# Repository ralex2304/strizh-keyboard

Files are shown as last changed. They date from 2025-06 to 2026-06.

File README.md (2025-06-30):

# [WIP] Strizh keyboard

**Strizh** (Russian for "swift") is an ultra low profile 44-48 key split with Kailh PG1316S switches

## Planned features

- ~9 mm thickness

- ZMK firmware

- NRF52840 SuperMini controllers

- optional 40 mm Cirque trackpad

- optional nice!view display

## PCB Draft

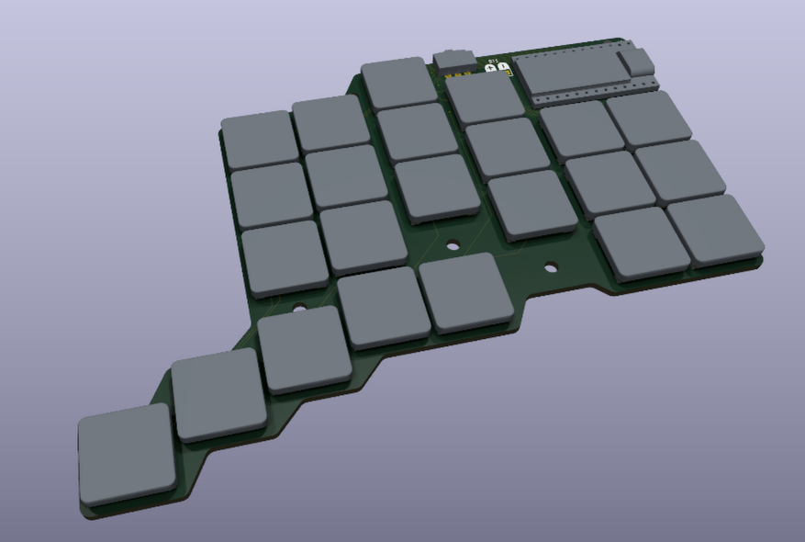
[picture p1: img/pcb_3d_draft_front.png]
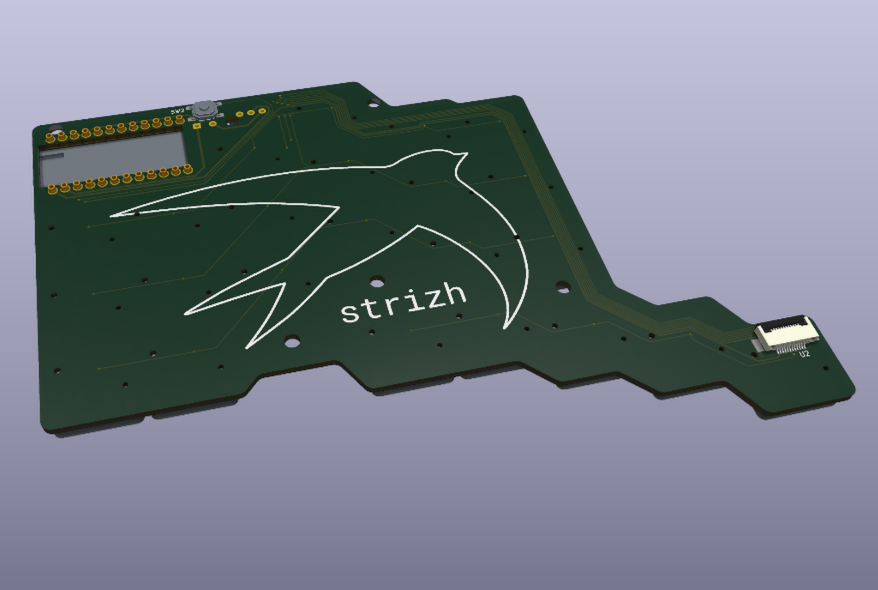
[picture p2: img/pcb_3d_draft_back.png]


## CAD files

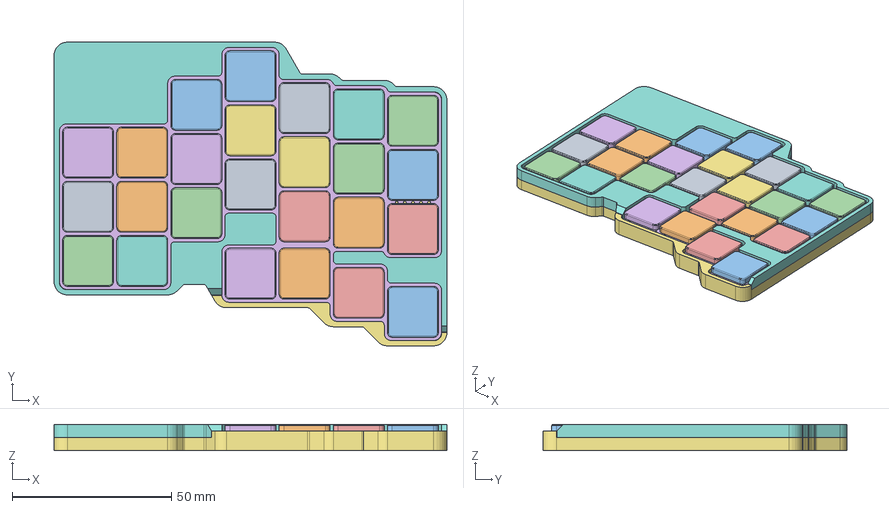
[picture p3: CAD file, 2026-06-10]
3D/case-left-7col/case-left-7col.FCStd
123.4 x 95.4 x 8.21 mm
sw_spst_5.2_5.2_1.5
left-7col_PCB

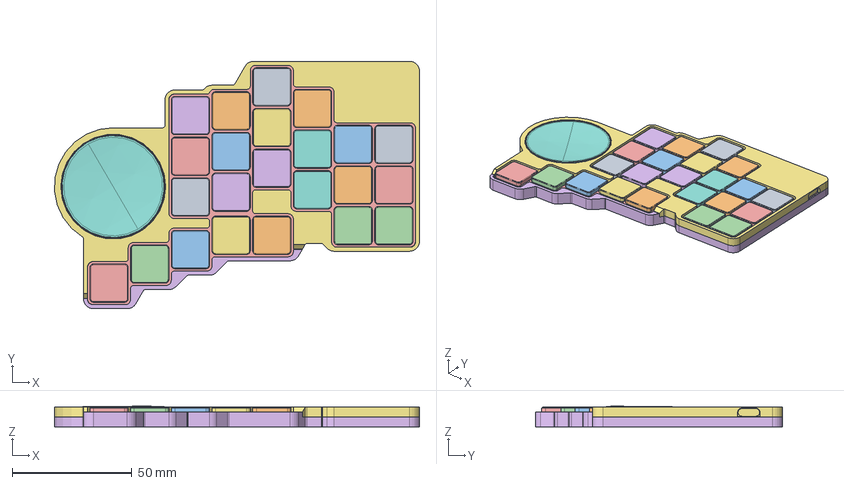
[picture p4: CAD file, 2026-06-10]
3D/case-right-trackpad/case-right-trackpad.FCStd
152.5 x 103.4 x 8.58 mm
sw_spst_5.2_5.2_1.5
FPC-12
FPC-013
FPC-014
FPC-015
FPC-016
FPC-017
FPC-018
FPC-019
FPC-020
FPC-021
FPC-022
FPC-023
FPC-024
FPC-025
FPC-026
FPC-027
FPC-028
right-trackpad_PCB

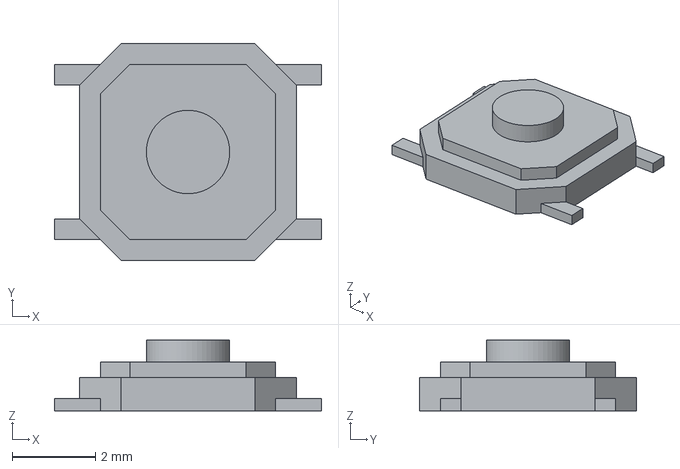
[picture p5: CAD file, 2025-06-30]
pcb/3D/sw_spst_5.2_5.2_1.5.step
6.40 x 5.20 x 1.70 mm

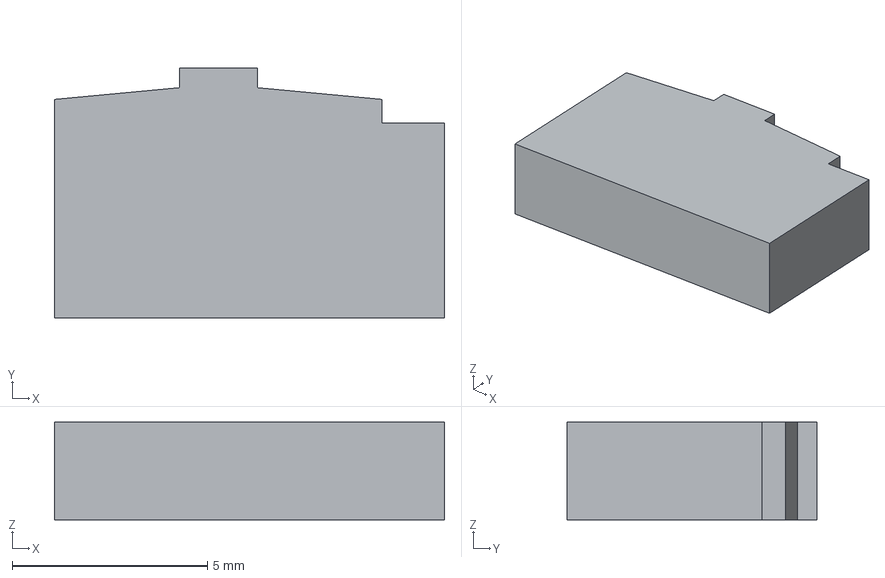
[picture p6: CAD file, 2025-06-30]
pcb/3D/bsi-10h.step
10.0 x 6.40 x 2.50 mm

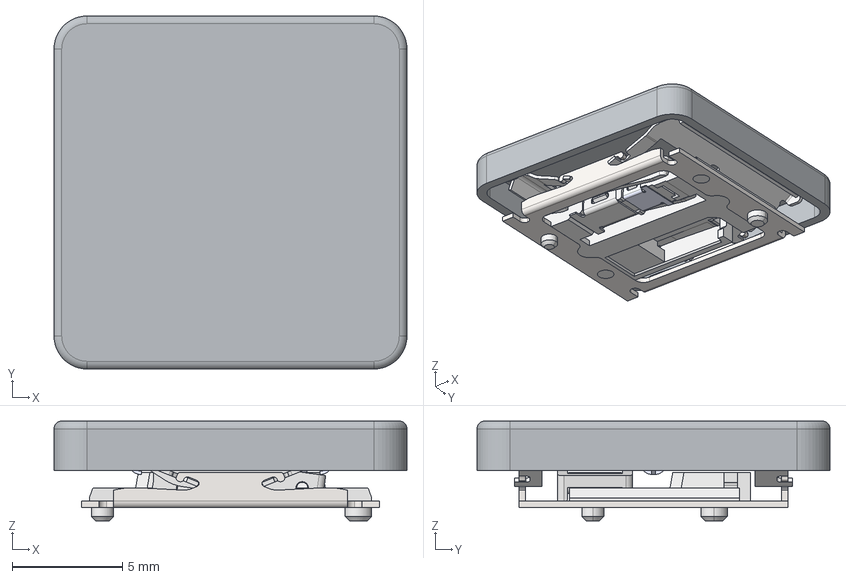
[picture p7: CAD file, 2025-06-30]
pcb/3D/PG1316S.step
16.0 x 16.0 x 4.53 mm
base
insolator
lever
left-wing
spring
right-pin
left-pin
right-wing

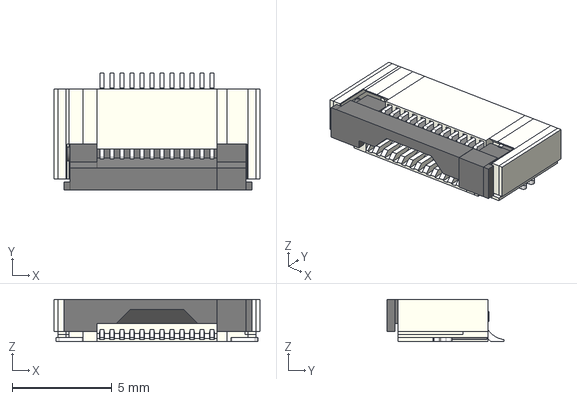
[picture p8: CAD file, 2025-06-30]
pcb/3D/FPC-12.stp
10.3 x 5.85 x 2.11 mm

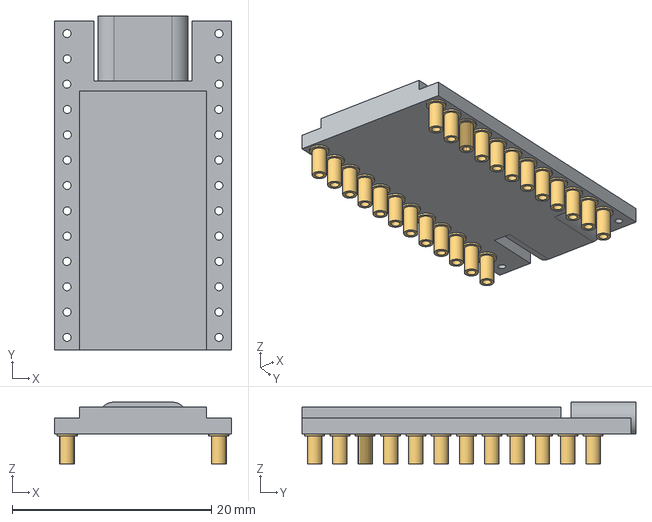
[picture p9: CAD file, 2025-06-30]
pcb/3D/supermini.step
17.8 x 33.5 x 6.20 mm

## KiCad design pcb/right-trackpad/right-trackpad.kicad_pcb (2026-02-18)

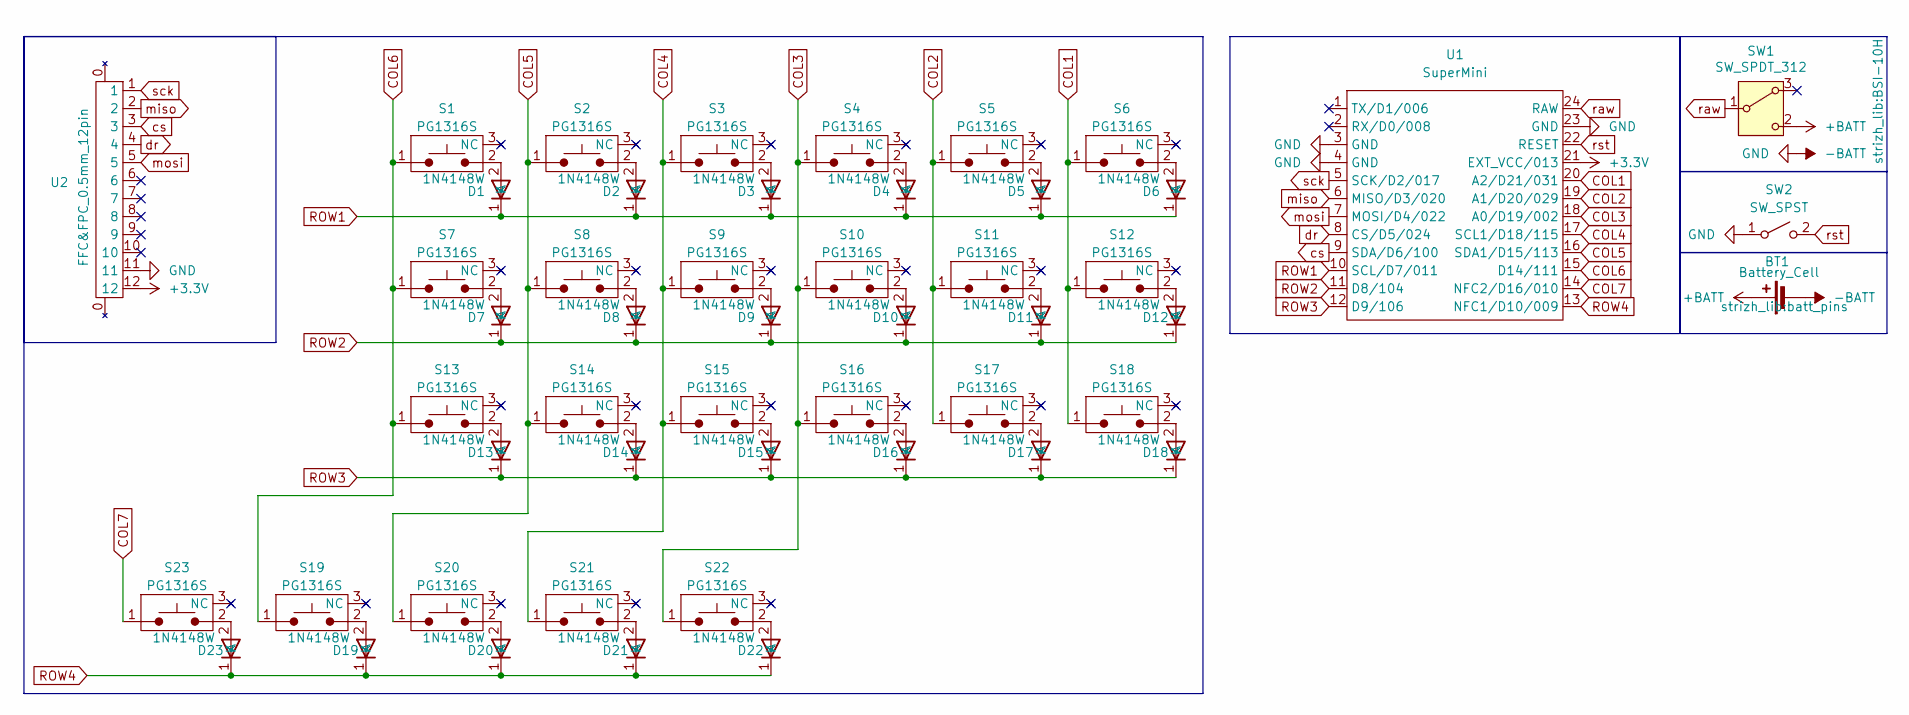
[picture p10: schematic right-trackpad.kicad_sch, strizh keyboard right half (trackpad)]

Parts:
BT1: Battery_Cell; batt_pins
D1, D2, D3, D4, D5, D6, D7, D8, D9, D10, D11, D12, D13, D14, D15, D16, D17, D18, D19, D20, D21, D22, D23: 1N4148W; 1N4148W_SOD-123
S1, S2, S3, S4, S5, S6, S7, S8, S9, S10, S11, S12, S13, S14, S15, S16, S17, S18, S19, S20, S21, S22, S23: PG1316S
SW1: SW_SPDT_312; BSI-10H
SW2: SW_SPST; SW_SPST_SKQG_WithStem
U1: SuperMini; supermini_nrf52840
U2: FFC&FPC_0.5mm_12pin

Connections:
+3.3V: U1.21 (EXT_VCC/013), U2.12
+BATT: BT1.1 (+), SW1.2 (C)
-BATT: BT1.2 (-), SW2.1 (A), U1.3 (GND), U1.4 (GND), U1.23 (GND), U2.11
COL1: S6.1, S12.1, S18.1, U1.20 (A2/D21/031)
COL2: S5.1, S11.1, S17.1, U1.19 (A1/D20/029)
COL3: S4.1, S10.1, S16.1, S22.1, U1.18 (A0/D19/002)
COL4: S3.1, S9.1, S15.1, S21.1, U1.17 (SCL1/D18/115)
COL5: S2.1, S8.1, S14.1, S20.1, U1.16 (SDA1/D15/113)
COL6: S1.1, S7.1, S13.1, S19.1, U1.15 (D14/111)
COL7: S23.1, U1.14 (NFC2/D16/010)
unnamed: D1.2 (A), S1.2
unnamed: D2.2 (A), S2.2
unnamed: D3.2 (A), S3.2
unnamed: D4.2 (A), S4.2
unnamed: D5.2 (A), S5.2
unnamed: D6.2 (A), S6.2
unnamed: D7.2 (A), S7.2
unnamed: D8.2 (A), S8.2
unnamed: D9.2 (A), S9.2
unnamed: D10.2 (A), S10.2
unnamed: D11.2 (A), S11.2
unnamed: D12.2 (A), S12.2
unnamed: D13.2 (A), S13.2
unnamed: D14.2 (A), S14.2
unnamed: D15.2 (A), S15.2
unnamed: D16.2 (A), S16.2
unnamed: D17.2 (A), S17.2
unnamed: D18.2 (A), S18.2
unnamed: D19.2 (A), S19.2
unnamed: D20.2 (A), S20.2
unnamed: D21.2 (A), S21.2
unnamed: D22.2 (A), S22.2
unnamed: D23.2 (A), S23.2
ROW1: D1.1 (K), D2.1 (K), D3.1 (K), D4.1 (K), D5.1 (K), D6.1 (K), U1.10 (SCL/D7/011)
ROW2: D7.1 (K), D8.1 (K), D9.1 (K), D10.1 (K), D11.1 (K), D12.1 (K), U1.11 (D8/104)
ROW3: D13.1 (K), D14.1 (K), D15.1 (K), D16.1 (K), D17.1 (K), D18.1 (K), U1.12 (D9/106)
ROW4: D19.1 (K), D20.1 (K), D21.1 (K), D22.1 (K), D23.1 (K), U1.13 (NFC1/D10/009)
cs: U1.9 (SDA/D6/100), U2.3
dr: U1.8 (CS/D5/024), U2.4
miso: U1.6 (MISO/D3/020), U2.2
mosi: U1.7 (MOSI/D4/022), U2.5
raw: SW1.1 (B), U1.24 (RAW)
rst: SW2.2 (B), U1.22 (RESET)
sck: U1.5 (SCK/D2/017), U2.1

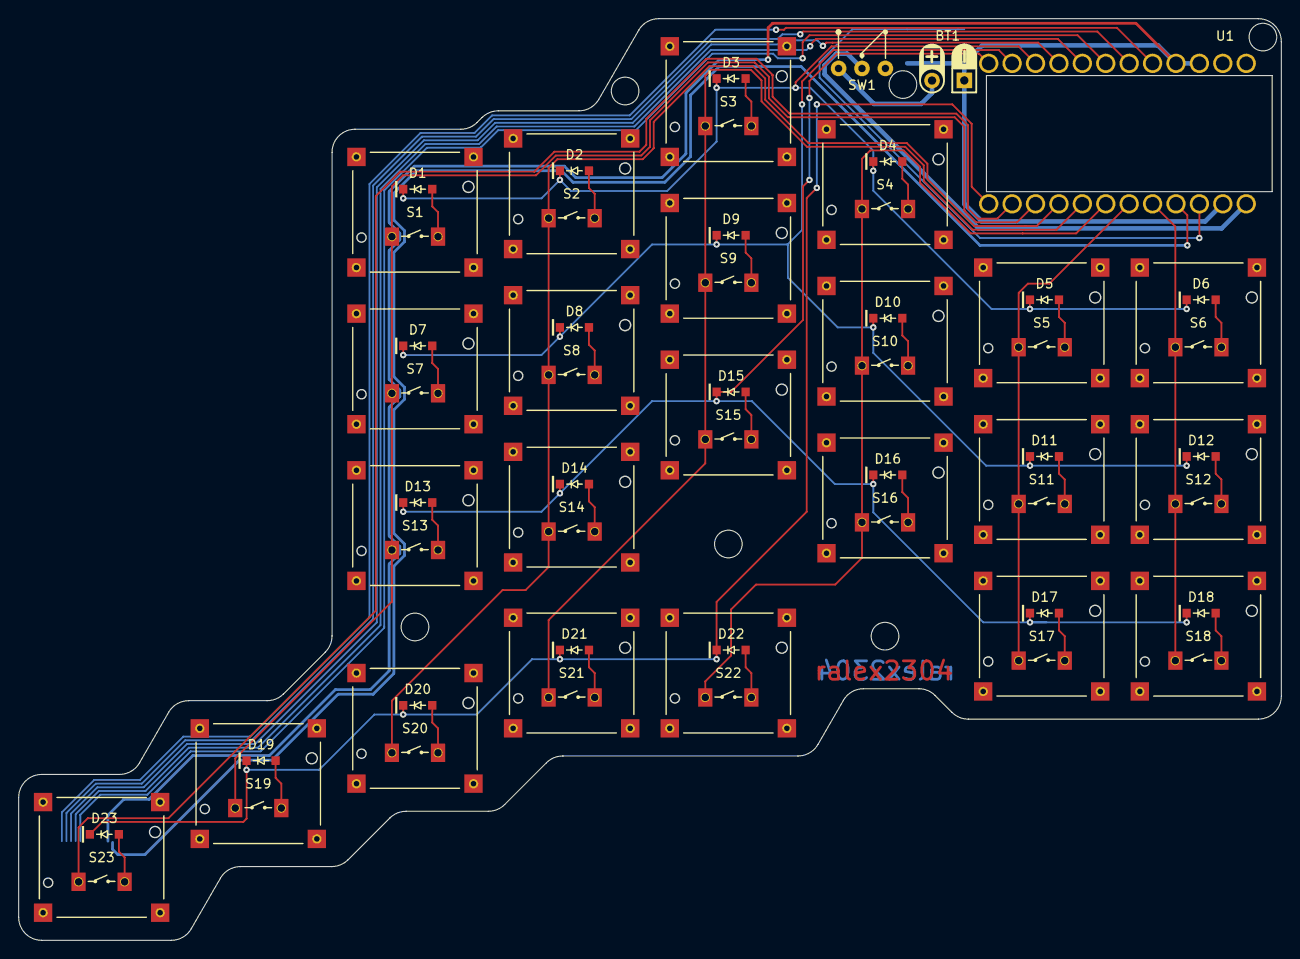
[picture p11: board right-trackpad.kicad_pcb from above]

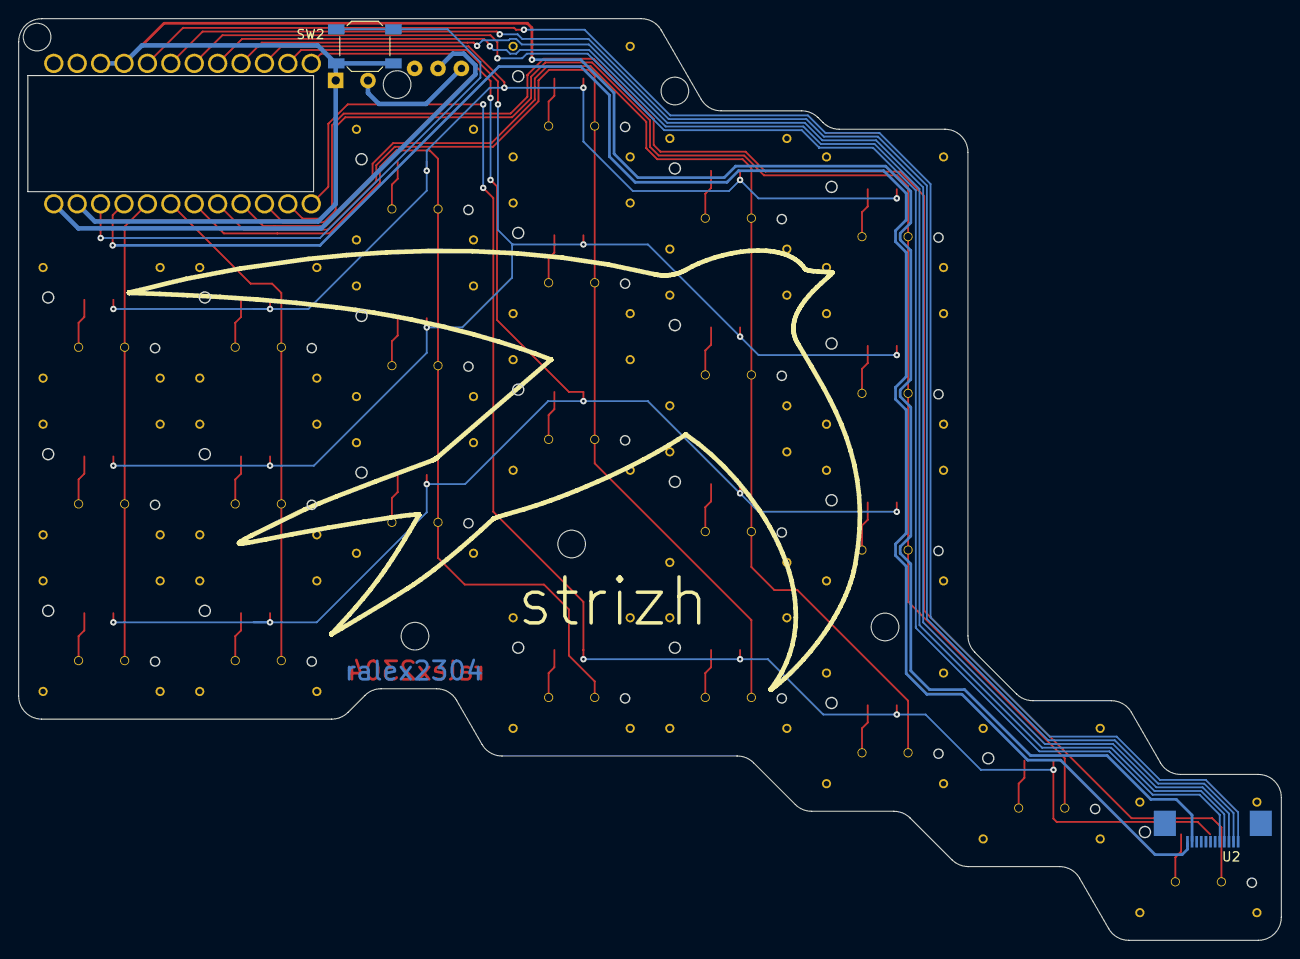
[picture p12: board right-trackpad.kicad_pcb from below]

Board: 2 copper layers, 137.0 x 100.0 mm, 51 parts (2 on the bottom side), 44 nets.

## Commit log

2025-06-30 Add right half pcb draft
    [FPC-12.stp, PG1316S.step, bsi-10h.step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]
2025-07-01 Add left half pcb draft
    [left-7col.kicad_pcb, left-7col.kicad_sch, right-trackpad.kicad_pcb]
2025-07-13 Change horizontal spacing and add nice!view to left half
    [left-7col.kicad_pcb, left-7col.kicad_sch, right-trackpad.kicad_pcb]
2025-07-20 Add vias to switch footprints
    [left-7col.kicad_pcb, right-trackpad.kicad_pcb]
2026-01-26 Fix pin naming of supermini
    [left-7col.kicad_pcb, left-7col.kicad_sch, right-trackpad.kicad_pcb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]
2026-02-18 Fix slight shift, enlarge vias to meet manufacturing requirements
    [left-7col.kicad_pcb, right-trackpad.kicad_pcb]
2026-02-23 Init left7col case
    [case-left-7col.FCStd]
2026-02-23 Add power switch chamfer
    [case-left-7col.FCStd]
2026-02-24 Add right trackpad case
    [case-left-7col.FCStd, case-right-trackpad.FCStd]
2026-02-28 Minor fixes after first draft print
    [case-left-7col.FCStd, case-right-trackpad.FCStd]
2026-03-01 Decrease top fillets, increase screw chamfers
    [case-left-7col.FCStd, case-right-trackpad.FCStd]
2026-03-03 Rework front part, create top-bottom coupling
    [case-left-7col.FCStd, case-right-trackpad.FCStd]
2026-03-08 Add latches
    [case-left-7col.FCStd, case-right-trackpad.FCStd]
2026-06-10 Final version
    [case-left-7col.FCStd, case-right-trackpad.FCStd]
